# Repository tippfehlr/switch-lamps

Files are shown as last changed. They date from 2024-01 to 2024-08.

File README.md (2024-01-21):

# switch-lamps

A switch for all my lamps 🛋️

## Goals

- Making it possible to control all lamps from one place
- Making multiple switches work together (no state stored on the switch unit)
- Needs to be foolproof
- Adding new lamps should be reasonably easy

## Hardware

### Lamps

Communication over a serial connection.

- One long wall with lamps
  - 4 zones
  - one warm and one cold led strip per zone
- 3 table lamps
- ceiling lamps
- a few floor lamps
- possibly more lamps in the future

### Inputs

- Slide up/down/left/right
- Press up/down/left/right
- Rotate left/right
- a proximity sensor

Sliding always also presses the corresponding button,
so sliding has to overwrite pressing.

### Outputs

- a Waveshare 1.54" B/W e-paper display
- the lamps, obviously

PCB design in `hardware/`.

### Microcontroller

Arduino ProMini 3.3V (8MHz)

The switch is powered over a long wire without much throughput,
which is also why the capacitors are needed.
They provide a buffer for updating the display.

## Software

- [avr-hal](https://github.com/Rahix/avr-hal) (currently my [fork](https://github.com/tippfehlr/avr-hal/tree/sparkfun-promini-3.3v) for `sparkfun-promini-3v3` support)
- [epd-waveshare](https://github.com/caemor/epd-waveshare) and [embedded-graphics](https://github.com/embedded-graphics/embedded-graphics) for the display

## current state

<p float="left">
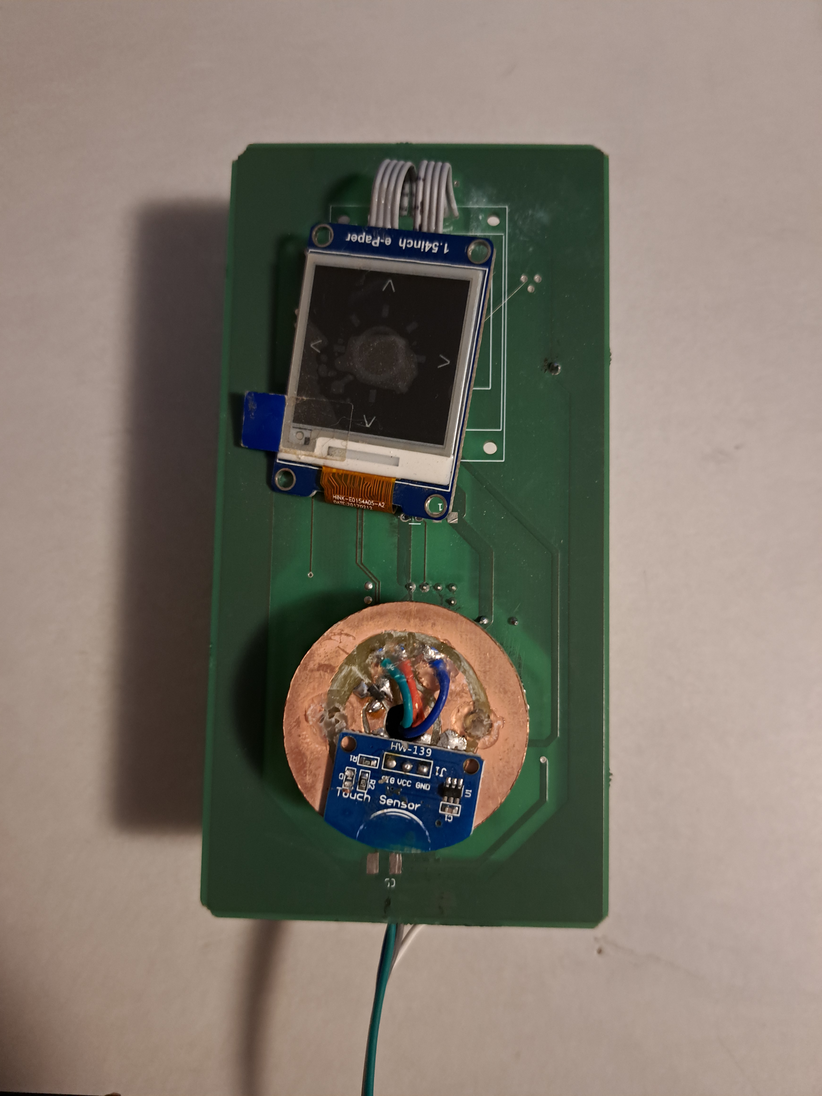
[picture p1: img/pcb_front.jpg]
  
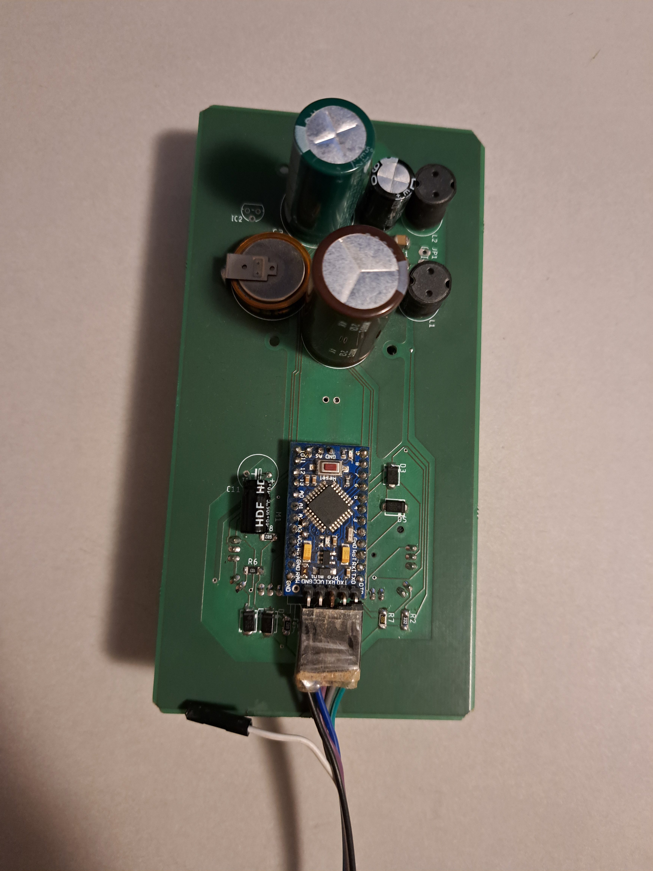
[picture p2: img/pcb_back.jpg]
   
</p>

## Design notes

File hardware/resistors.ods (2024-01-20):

 |  |  |  |  |  | result
2 |  |  | 0.77 |  |  | 0.77
 | 1.23 |  |  | 0.52 |  | 0.52
3.2 |  | 1.53 | 1.08 |  | 0.62 | 0.62
 |  |  |  |  |  | 1.08
6.6 |  | 2.42 | 1.65 |  | 0.89
 | 3.98 |  |  | 1.24 |  | 0.89
10 |  |  | 1.99 |  |  | 1.65
 |  |  |  |  |  | 1.24
 |  |  |  |  |  | 1.99
6.6
3.3 |  | 1.2 | 3.2 | 2.4
1024
 |  | 2.0 |  | 10.0
 |  | 1.5 | 6.6 | 4.0

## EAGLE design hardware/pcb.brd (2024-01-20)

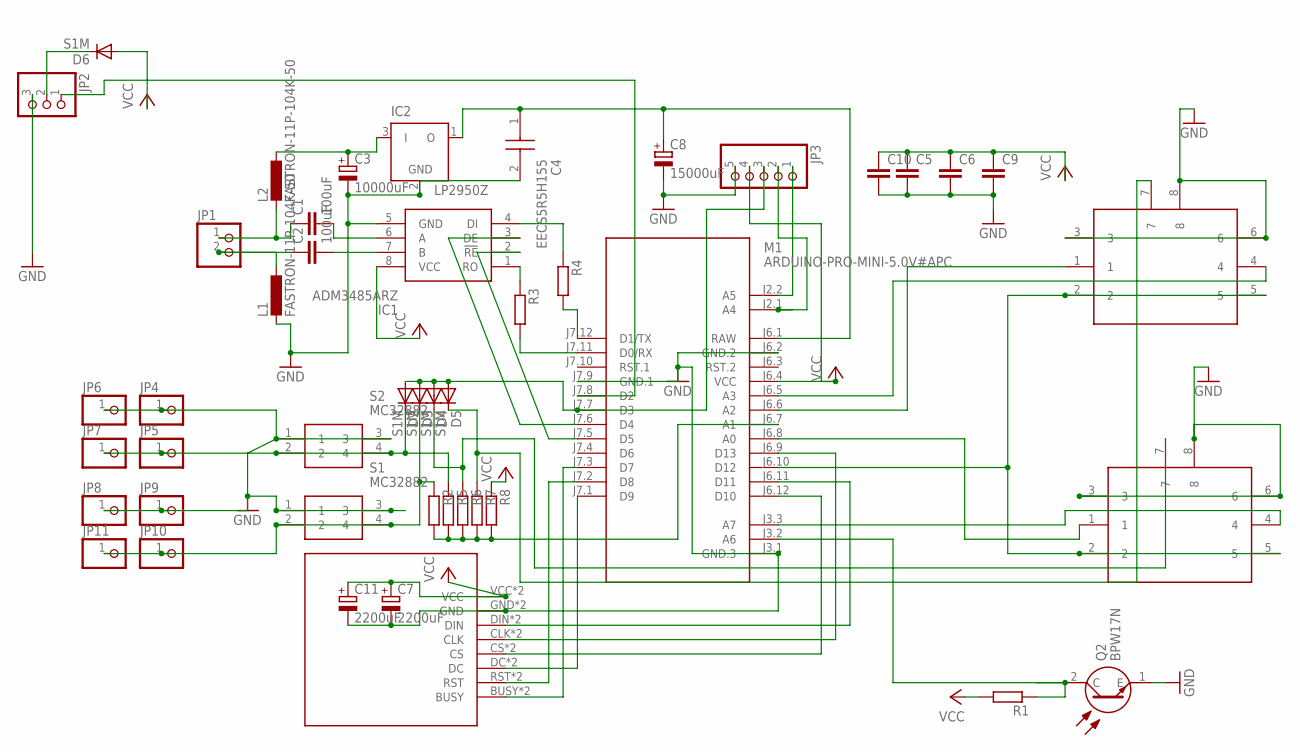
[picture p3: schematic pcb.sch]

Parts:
C1, C2: 100uF; C1210
C3: 10000uF; E7,5-18
C4: EECS5R5H155; SG(H)
C5, C6, C9, C10: C-EUC1812; C1812
C7, C11: 2200uF; TT5D9
C8: 15000uF; E7,5-18
D2, D3, D4, D5, D6: S1M; SMA
IC1: ADM3485ARZ; SOIC127P600X175-8N
IC2: LP2950Z; TO92
JP1: PINHD-1X2; 1X02
JP2: PINHD-1X3; 1X03
JP3: PINHD-1X55X2MM; 1_05X2MM
JP4, JP5, JP6, JP7, JP8, JP9, JP10, JP11: PINHD-1X1; 1X01
L1, L2: FASTRON-11P-104K-50; E5-10,5
M1: ARDUINO-PRO-MINI-5.0V#APC; ARDUINO-PRO-MINI#APC
Q2: BPW17N
R1, R2, R3, R4, R5, R6, R7, R8: R-EU_R1206; R1206
S1, S2: MC32882
U$1, U$2: FJ08K-S
U$3: 1,54-E-PAPER

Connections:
A: C1.2, IC1.6 (A)
A1: C1.1, JP1.1, L2.- (2)
B: C2.2, IC1.7 (B)
B1: C2.1, JP1.2, L1.+ (1)
GND: C3.-, C4.2, C5.2, C6.2, C7.-, C8.-, C9.2, C10.2, C11.-, IC1.5 (GND), IC2.2 (GND), JP2.3, JP3.5, JP4.1, JP6.1, JP8.1, JP9.1, L1.- (2), M1.J3.1 (GND.3), M1.J6.2 (GND.2), M1.J7.9 (GND.1), Q2.1 (E), S1.1, S1.3, S2.1, S2.3, U$1.3, U$1.6, U$1.8, U$2.3, U$2.6, U$2.8, U$3.GND, U$3.GND1 (GND)
unnamed: M1.J6.8 (A0), U$2.1
unnamed: D2.C, JP5.1, JP7.1, R5.1, S2.2, S2.4
unnamed: JP3.1, M1.J2.2 (A5)
unnamed: M1.J7.3 (D7), U$3.BUSY, U$3.BUSY1 (BUSY)
unnamed: M1.J7.2 (D8), U$3.RST, U$3.RST1 (RST)
unnamed: M1.J7.1 (D9), U$3.DC, U$3.DC1 (DC)
unnamed: M1.J6.12 (D10), U$3.CS, U$3.CS1 (CS)
unnamed: M1.J6.9 (D13), U$3.CLK, U$3.CLK1 (CLK)
unnamed: M1.J6.11 (D11), U$3.DIN, U$3.DIN1 (DIN)
unnamed: M1.J6.10 (D12), U$1.2, U$1.5, U$2.2, U$2.5
unnamed: M1.J3.3 (A7), U$2.4
unnamed: D5.C, R7.1, U$1.7
unnamed: M1.J6.6 (A2), U$1.1
unnamed: M1.J6.5 (A3), U$1.4
unnamed: D4.C, R6.1, U$2.7
unnamed: M1.J3.2 (A6), Q2.2 (C), R1.1
unnamed: M1.J7.11 (D0/RX), R3.2
unnamed: C3.+, IC2.3 (I), L2.+ (1)
unnamed: IC1.3 (DE), M1.J7.6 (D4)
unnamed: IC1.4 (DI), R4.1
unnamed: M1.J7.12 (D1/TX), R4.2
unnamed: D6.C, JP2.2
unnamed: IC1.1 (RO), R3.1
unnamed: JP2.1, M1.J7.8 (D2)
unnamed: IC1.2 (!RE), M1.J7.5 (D5)
unnamed: M1.J6.7 (A1), R2.2, R5.2, R6.2, R7.2, R8.2
unnamed: D2.A, D3.A, D4.A, D5.A, JP3.3, M1.J7.7 (D3)
unnamed: JP3.2, M1.J2.1 (A4)
unnamed: D3.C, JP10.1, JP11.1, R2.1, S1.2, S1.4
RAW: C4.1, C8.+, IC2.1 (O), M1.J6.1 (RAW)
VCC: C5.1, C6.1, C7.+, C9.1, C10.1, C11.+, D6.A, IC1.8 (VCC), JP3.4, M1.J6.4 (VCC), R1.2, R8.1, U$3.VCC, U$3.VCC1 (VCC)

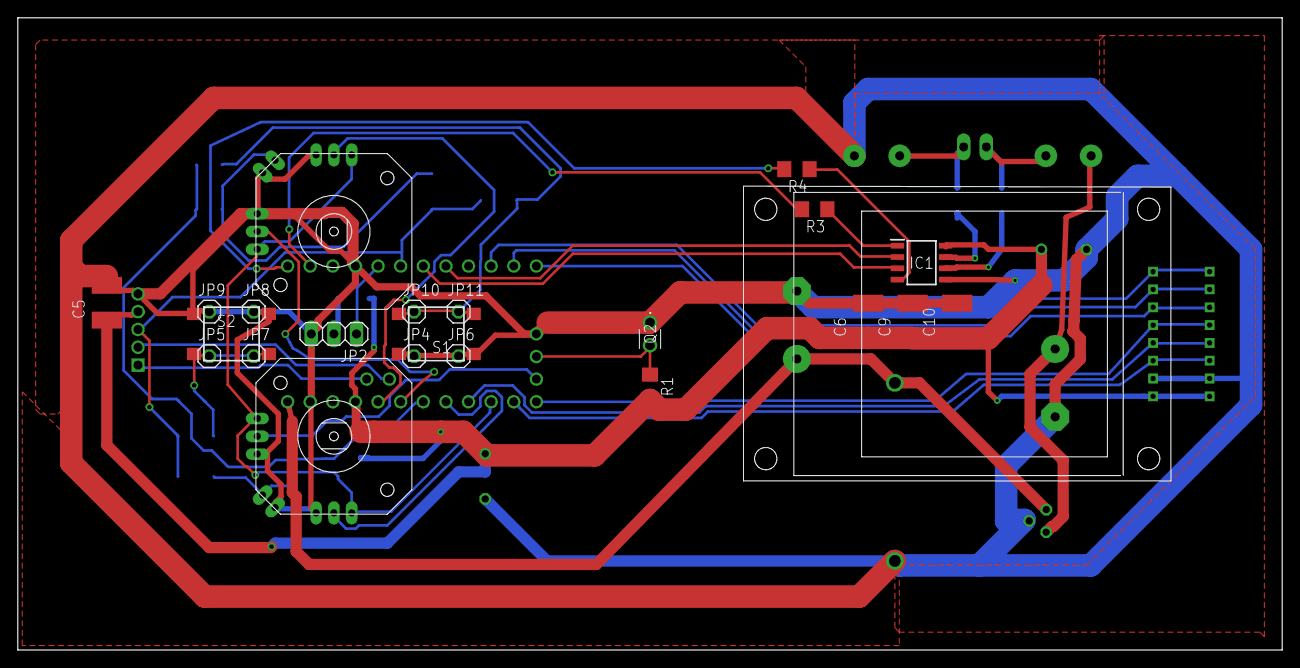
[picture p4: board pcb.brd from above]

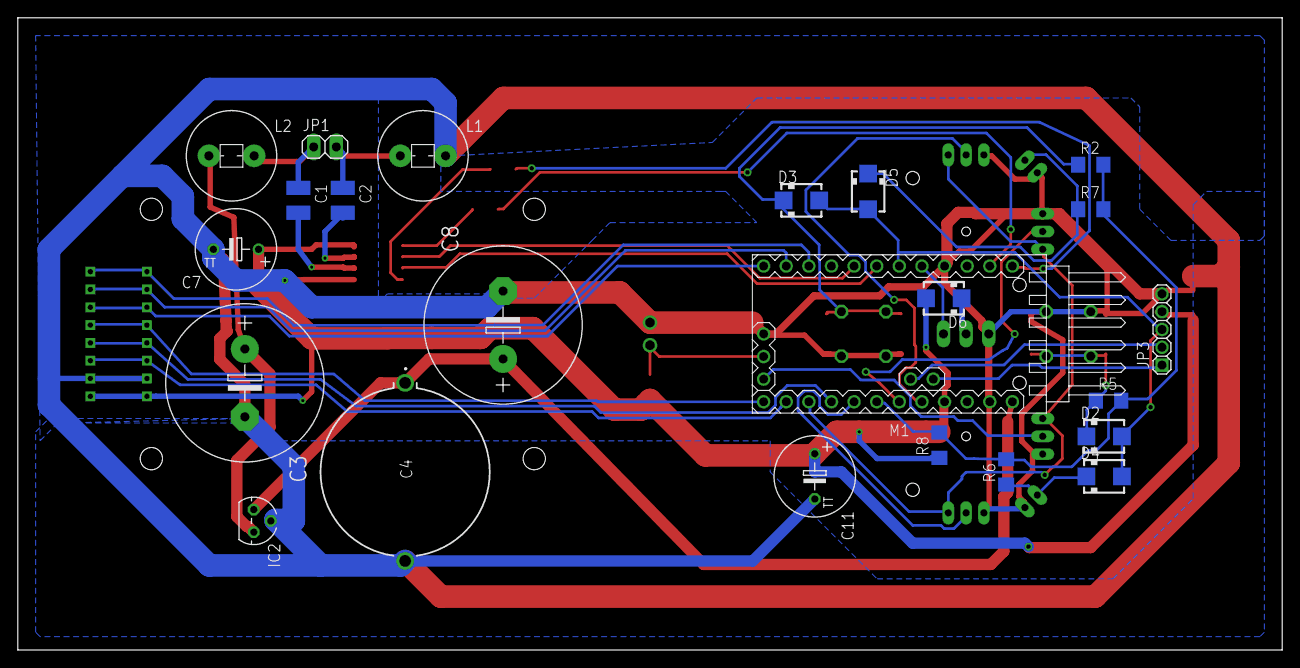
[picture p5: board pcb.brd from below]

Board: 2 copper layers, 142.0 x 71.0 mm, 46 parts (23 on the bottom side), 36 nets.

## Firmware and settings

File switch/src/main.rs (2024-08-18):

#![no_std]
#![no_main]
#![feature(abi_avr_interrupt)]

mod display;
mod enums;
mod millis;
mod sleep;

use display::Display;
use enums::{Button, MenuState};
use millis::{millis, millis_init};

use embedded_graphics::{
    mono_font::{iso_8859_9::FONT_9X15_BOLD, MonoTextStyle},
    pixelcolor::BinaryColor,
    prelude::*,
    text::{Alignment, Baseline, Text, TextStyleBuilder},
};
use epd_waveshare::{epd1in54::Epd1in54, prelude::*};

use arduino_hal::{
    adc, delay_ms,
    hal::{delay::Delay, Atmega},
    usart::UsartOps,
    Usart,
};
use core::time::Duration;
use panic_halt as _;
use sleep::{configure_int0, set_sleep_mode};
use ufmt::uwriteln;

const CHANGE_PER_SECOND: i8 = 64;
const BUTTON_HOLD_FREQUENCY: i8 = 25;
const BUTTON_HOLD_INTERVAL: Duration = Duration::from_millis(1000 / BUTTON_HOLD_FREQUENCY as u64);
const MENU_TIMEOUT: Duration = Duration::from_secs(5);

// must not evaluate to 0
const CHANGE_PER_INTERVAL: i8 = CHANGE_PER_SECOND / BUTTON_HOLD_FREQUENCY;

// #[link_section = ".rodata"]
// static LAMP1: [u8; 200 * 200 / 8] = [];

#[arduino_hal::entry]
fn main() -> ! {
    let dp = arduino_hal::Peripherals::take().unwrap();
    let pins = arduino_hal::pins!(dp);
    let mut serial = arduino_hal::default_serial!(dp, pins, 115200);
    let mut adc = arduino_hal::Adc::new(dp.ADC, Default::default());
    millis_init(&dp.TC0);

    set_sleep_mode(&dp.CPU.smcr);
    configure_int0(&dp.EXINT.eicra);

    unsafe { avr_device::interrupt::enable() };

    // this is the base voltage for the potis
    // when disabled, potis will not work
    let mut _poti_power = pins.d12.into_output_high();

    let dir_buttons = pins.a1.into_analog_input(&mut adc);
    let poti_left_x = pins.a0.into_analog_input(&mut adc);
    let poti_left_y = pins.a2.into_analog_input(&mut adc);
    let poti_right_x = pins.a3.into_analog_input(&mut adc);
    // poti_right_y is read with
    // adc.read_blocking(&adc::channel::ADC7)

    // proximity is somehow broken in hardware
    let _proximity = pins.d2.into_pull_up_input();

    // write 6x 0x00 to signal a restart
    for _ in 0..6 {
        serial.write_byte(0x00);
    }
    serial.write_byte(b'\n');

    // TODO: correct pins

    // let (mut spi, _) = arduino_hal::Spi::new(
    //     dp.SPI,
    //     pins.d13.into_output(),
    //     pins.d11.into_output(),
    //     pins.d4.into_pull_up_input(),
    //     pins.d10.into_output(),
    //     arduino_hal::spi::Settings::default(),
    // );
    // let cs_pin = pins.d5.into_output();
    // let busy_in = pins.d6.into_pull_up_input();
    // let dc = pins.d7.into_output();
    // let rst = pins.d8.into_output();

    // let pre_epd = Epd1in54::new(
    //     &mut spi,
    //     cs_pin,
    //     busy_in,
    //     dc,
    //     rst,
    //     &mut Delay::<MHz16>::new(),
    // );

    // uwriteln!(&mut serial, "{:#?}", pre_epd.is_err()).unwrap();

    // if pre_epd.is_err() {
    //     serial.write_byte(b'F');
    //     loop {}
    // }

    // let epd = pre_epd.unwrap();

    // let mut display: Display = Display::new(epd, spi);

    let mut button: Button;
    let mut last_button: Button = Button::None;
    let mut last_button_hold_time: Duration = Duration::ZERO;

    let mut menu_state: MenuState = MenuState::Main;
    let mut menu_state_timeout: Duration = Duration::ZERO;

    loop {
        // // proximity test
        //
        // if _proximity.is_high() {
        //     serial.write_byte(255);
        // } else {
        //     serial.write_byte(0);
        // }
        // delay_ms(100);
        // continue;

        button = Button::None;

        // if millis() - menu_state_timeout >= MENU_TIMEOUT {
        //     menu_state = MenuState::Main;
        //     // update_display(&menu_state, &mut display);
        // }

        match dir_buttons.analog_read(&mut adc) {
            500...520 => button = Button::PressBottom,
            370...390 => button = Button::PressRight,
            180...200 => button = Button::PressLeft,
            330...340 => button = Button::PressTop,
            _ => {}
        }

        // sliding overwrites pressing
        match (
            poti_left_x.analog_read(&mut adc),
            poti_left_y.analog_read(&mut adc),
            poti_right_x.analog_read(&mut adc),
            adc.read_blocking(&adc::channel::ADC7),
        ) {
            (0.., 0...200, 0.., 900..) => button = Button::RotateRight,
            (0.., 900.., 0.., 0...200) => button = Button::RotateLeft,
            (0.., 800.., 0.., 800..) => button = Button::SlideDown,
            (0.., 0...200, 0.., 0...200) => button = Button::SlideUp,
            (900.., 0.., 0...200, 0..) => button = Button::SlideRight,
            (0...200, 0.., 900.., 0..) => button = Button::SlideLeft,
            _ => {}
        };

        if button != Button::None
            && (button != last_button || millis() - last_button_hold_time >= BUTTON_HOLD_INTERVAL)
        {
            last_button = button.clone();
            last_button_hold_time = millis();
            menu_state_timeout = millis();

            match button {
                Button::RotateRight => send_data(
                    &mut serial,
                    get_mask(&menu_state),
                    CHANGE_PER_INTERVAL,
                    0,
                    0,
                ),
                Button::RotateLeft => send_data(
                    &mut serial,
                    get_mask(&menu_state),
                    -CHANGE_PER_INTERVAL,
                    0,
                    0,
                ),
                Button::SlideUp => send_data(
                    &mut serial,
                    get_mask(&menu_state),
                    0,
                    CHANGE_PER_INTERVAL,
                    0,
                ),
                Button::SlideDown => send_data(
                    &mut serial,
                    get_mask(&menu_state),
                    0,
                    -CHANGE_PER_INTERVAL,
                    0,
                ),
                Button::SlideLeft => send_data(
                    &mut serial,
                    get_mask(&menu_state),
                    0,
                    0,
                    -CHANGE_PER_INTERVAL,
                ),
                Button::SlideRight => send_data(
                    &mut serial,
                    get_mask(&menu_state),
                    0,
                    0,
                    CHANGE_PER_INTERVAL,
                ),
                Button::PressTop => {
                    // match &menu_state {
                    //     MenuState::Lamp1 => {
                    //         send_data(&mut serial, get_mask(&menu_state), -127, 0, 0)
                    //     }
                    //     _ => {
                    //         menu_state = MenuState::Lamp1;
                    //         menu_state_timeout = millis();
                    //
                    //         // update_display(&menu_state, &mut display);
                    //     }
                    // }
                }
                Button::PressBottom => {
                    // match menu_state {
                    //     MenuState::Lamp2 => {
                    //         send_data(&mut serial, get_mask(&menu_state), -127, 0, 0)
                    //     }
                    //     _ => {
                    //         menu_state = MenuState::Lamp2;
                    //         menu_state_timeout = millis();
                    //
                    //         // update_display(&menu_state, &mut display);
                    //     }
                    // }
                }
                Button::PressLeft => {
                    // increment_menu_state(&mut menu_state);

                    // update_display(&menu_state, &mut display);
                }
                Button::PressRight => {
                    // decrement_menu_state(&mut menu_state);

                    // update_display(&menu_state, &mut display);
                }
                Button::None => unreachable!(),
            }
        }
        // uwriteln!(
        //     &mut serial,
        //     "dir_buttons: {:?}, poti_left_x: {:?}, poti_left_y: {:?}, poti_right_x: {:?}, poti_right_y: {:?}, hand: {:?}, button: {:?}",
        //     dir_buttons.analog_read(&mut adc),
        //     poti_left_x.analog_read(&mut adc),
        //     poti_left_y.analog_read(&mut adc),
        //     poti_right_x.analog_read(&mut adc),
        //     adc.read_blocking(&adc::channel::ADC7),
        //     adc.read_blocking(&adc::channel::ADC6),
        //     button
        // )
        // .unwrap();
        // delay_ms(1000);
    }
}

fn update_display(menu_state: &MenuState, display: &mut Display) {
    let display_middle = Point {
        x: display.epd.width() as i32 / 2,
        y: display.epd.height() as i32 / 2,
    };
    let character_style = MonoTextStyle::new(&FONT_9X15_BOLD, BinaryColor::On);
    let text_style = TextStyleBuilder::new()
        .alignment(Alignment::Center)
        .baseline(Baseline::Middle)
        .build();
    match menu_state {
        MenuState::Main => {
            // display.epd.update_and_display_frame(&mut display.spi, buffer, &mut display.delay);
            Text::with_text_style("ALL", display_middle, character_style, text_style);
            display.display_frame();
        }
        MenuState::Lamp1 => {
            Text::with_text_style("1", display_middle, character_style, text_style);
            display.display_frame();
        }
        MenuState::Lamp2 => {
            Text::with_text_style("2", display_middle, character_style, text_style);
            display.display_frame();
        }
    }
}

fn increment_menu_state(menu_state: &mut MenuState) {
    match menu_state {
        MenuState::Main => *menu_state = MenuState::Lamp1,
        MenuState::Lamp1 => *menu_state = MenuState::Lamp2,
        MenuState::Lamp2 => *menu_state = MenuState::Main,
    }
}

fn decrement_menu_state(menu_state: &mut MenuState) {
    match menu_state {
        MenuState::Main => *menu_state = MenuState::Lamp2,
        MenuState::Lamp2 => *menu_state = MenuState::Lamp1,
        MenuState::Lamp1 => *menu_state = MenuState::Main,
    }
}

fn get_mask(menu_state: &MenuState) -> u16 {
    match menu_state {
        MenuState::Main => 0b1111111111111111,
        MenuState::Lamp1 => 0b0000000000001111,
        MenuState::Lamp2 => 0b0000000001110000,
    }
}

/// send data to lamps
/// * `serial`: serial interface
/// * `mask`: 16 bit mask
/// * `brightness`: -127 to 127 (relative)
/// * `gamma`: -127 to 127 (red < blue, relative)
/// * `position`: -127 to 127 (left < right, relative)
fn send_data<U, P1, P2>(
    serial: &mut Usart<U, P1, P2>,
    mask: u16,
    brightness: i8,
    gamma: i8,
    position: i8,
) where
    U: UsartOps<Atmega, P1, P2>,
{
    serial.write_byte(0x00);
    serial.write_byte((mask >> 8) as u8);
    serial.write_byte(mask as u8);
    serial.write_byte(brightness as u8);
    serial.write_byte(gamma as u8);
    serial.write_byte(position as u8);
    serial.write_byte(b'\n');
    serial.flush();
}

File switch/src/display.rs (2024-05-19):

use embedded_graphics::{pixelcolor::BinaryColor, prelude::*};
use epd_waveshare::{epd1in54::Epd1in54, prelude::*};

use arduino_hal::{
    clock::MHz16,
    hal::{
        delay::Delay,
        port::{PB0, PD5, PD6, PD7},
        Spi,
    },
    port::{
        mode::{Input, Output, PullUp},
        Pin,
    },
};

pub type Epd = Epd1in54<
    Spi,
    Pin<Output, PD5>,
    Pin<Input<PullUp>, PD6>,
    Pin<Output, PD7>,
    Pin<Output, PB0>,
    Delay<MHz16>,
>;
// the same with dynamic pins; use .downgrade() to convert. Comes with a performance penalty. not tested.
// type Epd = Epd1in54<Spi, Pin<Output>, Pin<Input<PullUp>>, Pin<Output>, Pin<Output>, Delay<MHz16>>;

pub enum DisplayError {}

pub struct Display {
    pub epd: Epd,
    spi: Spi,
    delay: Delay<MHz16>,
}

impl Display {
    pub fn new(epd: Epd, spi: Spi) -> Self {
        let delay = Delay::<MHz16>::new();
        Self { epd, spi, delay }
    }
    pub fn display_frame(&mut self) {
        self.epd
            .display_frame(&mut self.spi, &mut self.delay)
            .unwrap();
    }
}

impl OriginDimensions for Display {
    fn size(&self) -> Size {
        Size {
            width: 200,
            height: 200,
        }
    }
}

fn to_color(color: BinaryColor) -> u8 {
    color.is_on() as u8 * 255
}

impl DrawTarget for Display {
    type Color = BinaryColor;
    type Error = DisplayError;
    fn draw_iter<I>(&mut self, draw: I) -> Result<(), DisplayError>
    where
        I: IntoIterator<Item = Pixel<Self::Color>>,
    {
        for pixel in draw {
            self.epd
                .update_partial_frame(
                    &mut self.spi,
                    &[to_color(pixel.1)],
                    pixel.0.x.try_into().unwrap(),
                    pixel.0.y.try_into().unwrap(),
                    1,
                    1,
                )
                .unwrap();
        }
        Ok(())
    }

    fn clear(&mut self, color: Self::Color) -> Result<(), Self::Error> {
        self.epd.set_background_color(to_color(color).into());
        self.epd
            .clear_frame(&mut self.spi, &mut self.delay)
            .unwrap();
        Ok(())
    }
}

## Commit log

2023-03-28 working millis(), interface model
2023-03-29 button & menu control structure
2023-05-29 DisplayBuffer struct commented out, otherwise compiling without errors
    [main.rs]
2023-06-08 dyn WaveshareDisplay is working but is dynamic. Epd1in54 should work but doesn’t
    WaveshareDisplay<SPI, Output, Input, Output, Output, Delay, DisplayColor = BinaryColor>
    Epd1in54<SPI, Output, Input, Output, Output, Delay>
    [main.rs]
2023-12-01 print raw data
2024-01-14 refactor: use sparkfun-promini-3v from arduino-hal
2024-01-14 fix: reverse slide/press direction
    [main.rs]
2024-01-20 add hardware files
    [pcb.brd, pcb.sch, resistors.ods]
2024-01-20 chore: rename to switch-lamps
2024-05-18 chore: move everything to switch/
2024-05-18 chore: move avr-specs to switch and create link from root
    apparently rust-analyzer expects it to be in the Cargo.toml folder, but
    cargo run needs it to be in the git root
2024-05-23 fix: reset menu timeout when any button is pressed, add 0x00 to beginning of message
    [main.rs]
2024-05-23 chore(deps): use Rahix’s version of avr-hal, rev-bound
    my repo was only for testing the poti bug
2024-05-23 fix: millis now uses arduino_hal::DefaultClock based on enabled features
2024-05-23 feat: set change rate per seconds to fix amount, set updates per second
    [main.rs]
2024-08-18 feat: add sleep functions, disable display mode switching for now

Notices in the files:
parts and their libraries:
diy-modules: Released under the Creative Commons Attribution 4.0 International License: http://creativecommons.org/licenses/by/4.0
